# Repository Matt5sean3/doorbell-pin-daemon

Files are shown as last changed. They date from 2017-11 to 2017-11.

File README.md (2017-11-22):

# Doorbell Pin Daemon

This is a simple program for controlling a Doorbell using a Raspberry Pi. With minor modifications this system should be usable with any Linux system that can control GPIOs via sysfs. Everything from board designs to the systemd service are included. This is still in development and ideally will be deployable as just a debian package on the Pi eventually.

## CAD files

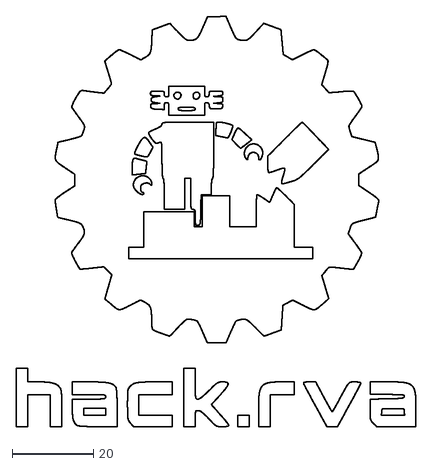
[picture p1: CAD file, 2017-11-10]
enclosure/Hackrobot.dxf
98.2 x 100.8

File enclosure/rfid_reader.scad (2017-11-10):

// Designed for the Parallax RFID Reader 28140
// A rather too expensive module

// 62.2 x 82.5 x 5.57 mm
// Use 3mm walls
// 3.5mm screw holes
// 54.5mm bolt center-to-center distance
// 75mm bolt center-to-center distance y
// 1.6mm 

// #6 machine screw holes

width = 62.3;
height = 82.6;
side_space = 1;
board_depth = 1.6;
standoff = 2;
electronics_depth = 4;
electronics_height = 15;
electronics_width = 47;
bolt_diameter = 9.5;
bolt_thickness = 3;
bolt_hole_diameter = 3.7;
plate_thickness = 3;
bolt_length = 18;

// connector hole 2.54 x 10.12
connector_width = 11;
connector_depth = 3;
connector_offset = 8;

wall_thickness = 2.5;

// to prevent rounding problems
del = 0.1;
front_thickness = max(wall_thickness, bolt_thickness + 1);
depth = bolt_length - plate_thickness;
bolt_offset = bolt_hole_diameter / 2 + 2.25;
bolt_hole_locations = [
  [bolt_offset, bolt_offset, 0],
  [width - bolt_offset, bolt_offset, 0],
  [bolt_offset, height - bolt_offset, 0],
  [width - bolt_offset, height - bolt_offset, 0]];

module rfid_reader_enclosure() {

  difference() {
    translate([-wall_thickness - side_space, -wall_thickness - side_space])
      cube([width + 2 * (wall_thickness + side_space), height + 2 * (wall_thickness + side_space), depth]);

    // void for the board and electronics
    difference() {
      translate([-side_space, -side_space, front_thickness])
        cube([2 * side_space + width, 2 * side_space + height, depth - front_thickness + del]);
      // standoffs for the board
      for(location = bolt_hole_locations) {
        translate(location)
          cylinder(d = bolt_diameter, h = front_thickness + standoff);
      }
    }

    // void for the connectors
    translate([connector_offset, -side_space - wall_thickness - del, front_thickness + board_depth + standoff - 0.25])
      cube([connector_width, wall_thickness + 2 * del, connector_depth]);

    // Bolt holes
    for(location = bolt_hole_locations) {
      translate(location)
      translate([0, 0, -del]) {
        cylinder(d = bolt_hole_diameter, h = depth, $fn = 20);
        cylinder(d = bolt_diameter, h = bolt_thickness, $fn = 6);
      }
    }

    // essentially placed manually
    translate([0, 0, -del])
    linear_extrude(height = min(0.5, wall_thickness / 2)) {
      translate([55, electronics_height, 0])
      scale(0.5)
      mirror([1, 0, 0])
      translate([-26, -18, 0])
        import("Hackrobot.dxf");
    }

  }
}

module rfid_spacer() {
  spacer_height = depth - front_thickness - standoff - board_depth;
  difference() {
    cylinder(d = bolt_diameter, h = spacer_height, $fn = 20);
    translate([0, 0, -del])
    cylinder(d = bolt_hole_diameter, h = spacer_height + 2 * del, $fn = 20);
  }
}

*rfid_reader_enclosure();

for(location = bolt_hole_locations) {
  translate([0, 0, front_thickness + standoff + board_depth])
  translate(location)
    rfid_spacer();
}

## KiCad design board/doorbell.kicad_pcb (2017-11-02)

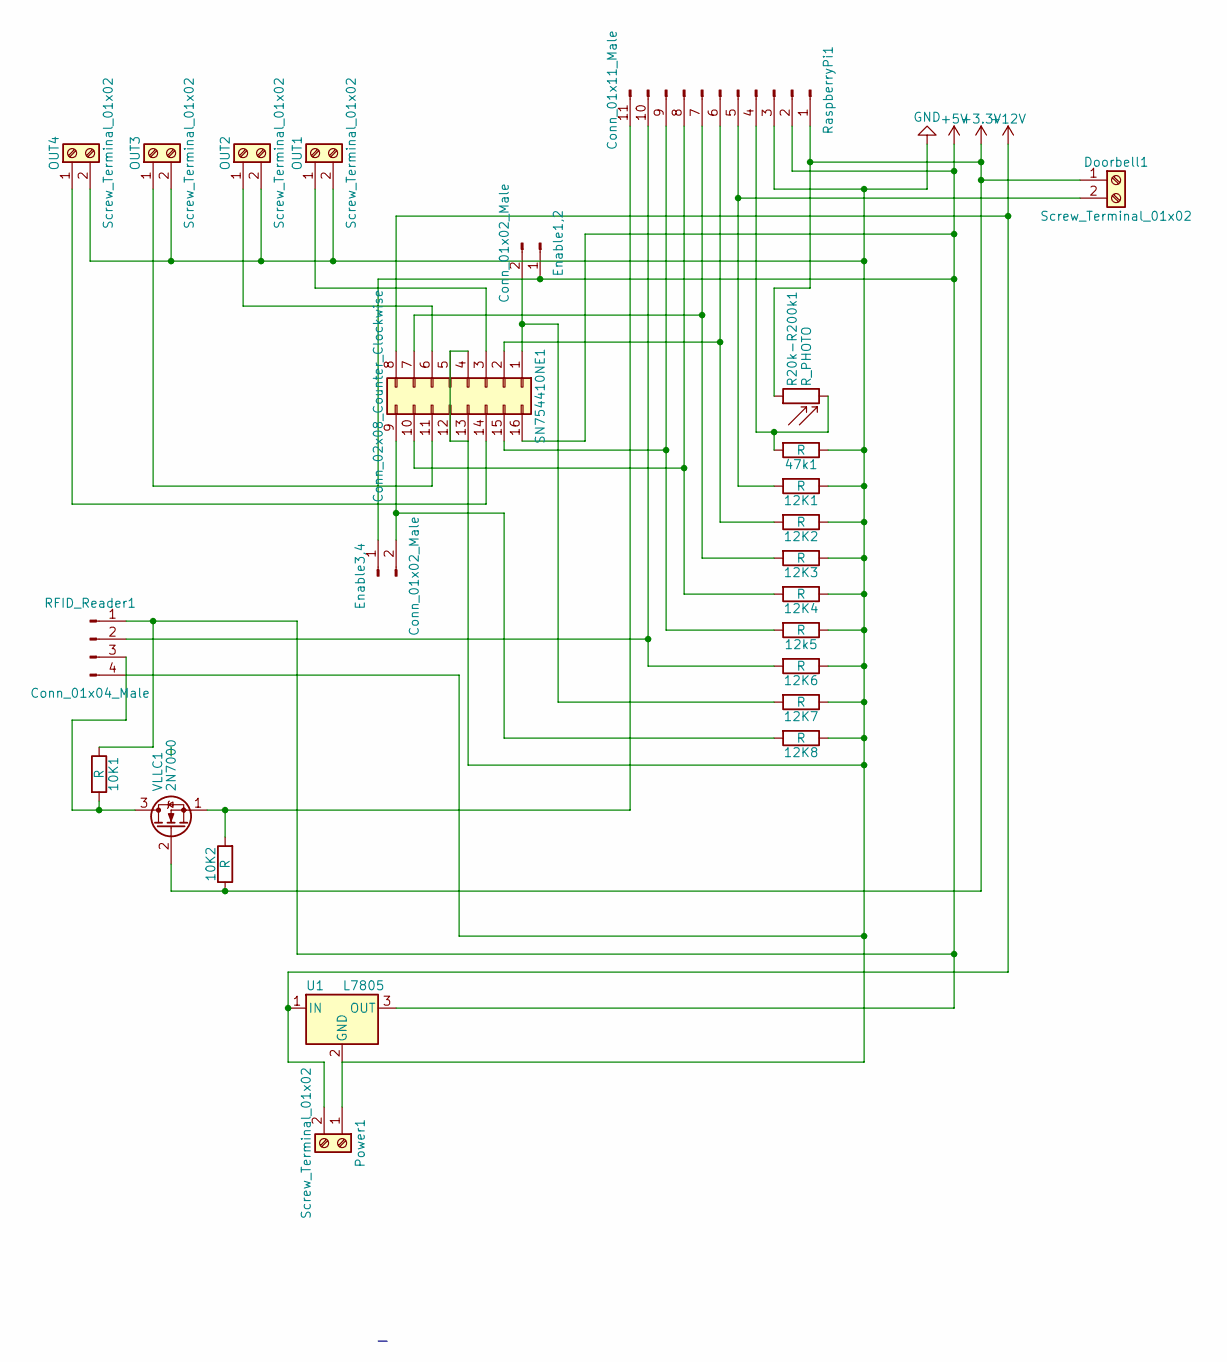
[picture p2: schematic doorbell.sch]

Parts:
10K1, 10K2: R; R_Axial_DIN0204_L3.6mm_D1.6mm_P7.62mm_Horizontal
12K1, 12K2, 12K3, 12K4, 12K6, 12K7, 12K8, 12k5, 47k1: R; R_Axial_DIN0207_L6.3mm_D2.5mm_P7.62mm_Horizontal
Doorbell1: Screw_Terminal_01x02; TerminalBlock_Philmore_TB132_02x5mm_Straight
Enable1,2, Enable3,4: Conn_01x02_Male; Pin_Header_Straight_1x02_Pitch2.54mm
OUT1, OUT2, OUT3, OUT4: Screw_Terminal_01x02; TerminalBlock_Philmore_TB132_02x5mm_Straight
Power1: Screw_Terminal_01x02; TerminalBlock_Philmore_TB132_02x5mm_Straight
R20k-R200k1: R_PHOTO; R_Axial_DIN0204_L3.6mm_D1.6mm_P5.08mm_Vertical
RFID_Reader1: Conn_01x04_Male; Pin_Header_Straight_1x04_Pitch2.54mm
RaspberryPi1: Conn_01x11_Male; Pin_Header_Straight_1x11_Pitch2.54mm
SN754410NE1: Conn_02x08_Counter_Clockwise; DIP-16_W7.62mm
U1: L7805; TO-220
VLLC1: 2N7000; TO-92_Inline_Wide

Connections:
+3V3: 10K2.1, Doorbell1.1, R20k-R200k1.1, RaspberryPi1.1, VLLC1.2 (G)
+5V: 10K1.1, Enable1,2.1, Enable3,4.1, RFID_Reader1.1, RaspberryPi1.2, SN754410NE1.16, U1.3 (OUT)
+12V: Power1.2, SN754410NE1.8, U1.1 (IN)
GND: 12K1.1, 12K2.1, 12K3.1, 12K4.1, 12K6.1, 12K7.1, 12K8.1, 12k5.1, 47k1.1, OUT1.2, OUT2.2, OUT3.2, OUT4.2, Power1.1, RFID_Reader1.4, RaspberryPi1.3, SN754410NE1.4, SN754410NE1.5, SN754410NE1.12, SN754410NE1.13, U1.2 (GND)
unnamed: 10K1.2, RFID_Reader1.3, VLLC1.3 (D)
unnamed: 10K2.2, RaspberryPi1.11, VLLC1.1 (S)
unnamed: 12K1.2, Doorbell1.2, RaspberryPi1.5
unnamed: 12K2.2, RaspberryPi1.6, SN754410NE1.2
unnamed: 12K3.2, RaspberryPi1.7, SN754410NE1.7
unnamed: 12K4.2, RaspberryPi1.8, SN754410NE1.10
unnamed: 12K6.2, RFID_Reader1.2, RaspberryPi1.10
unnamed: 12K7.2, Enable1,2.2, SN754410NE1.1
unnamed: 12K8.2, Enable3,4.2, SN754410NE1.9
unnamed: 12k5.2, RaspberryPi1.9, SN754410NE1.15
unnamed: 47k1.2, R20k-R200k1.2, RaspberryPi1.4
unnamed: OUT1.1, SN754410NE1.3
unnamed: OUT2.1, SN754410NE1.6
unnamed: OUT3.1, SN754410NE1.11
unnamed: OUT4.1, SN754410NE1.14

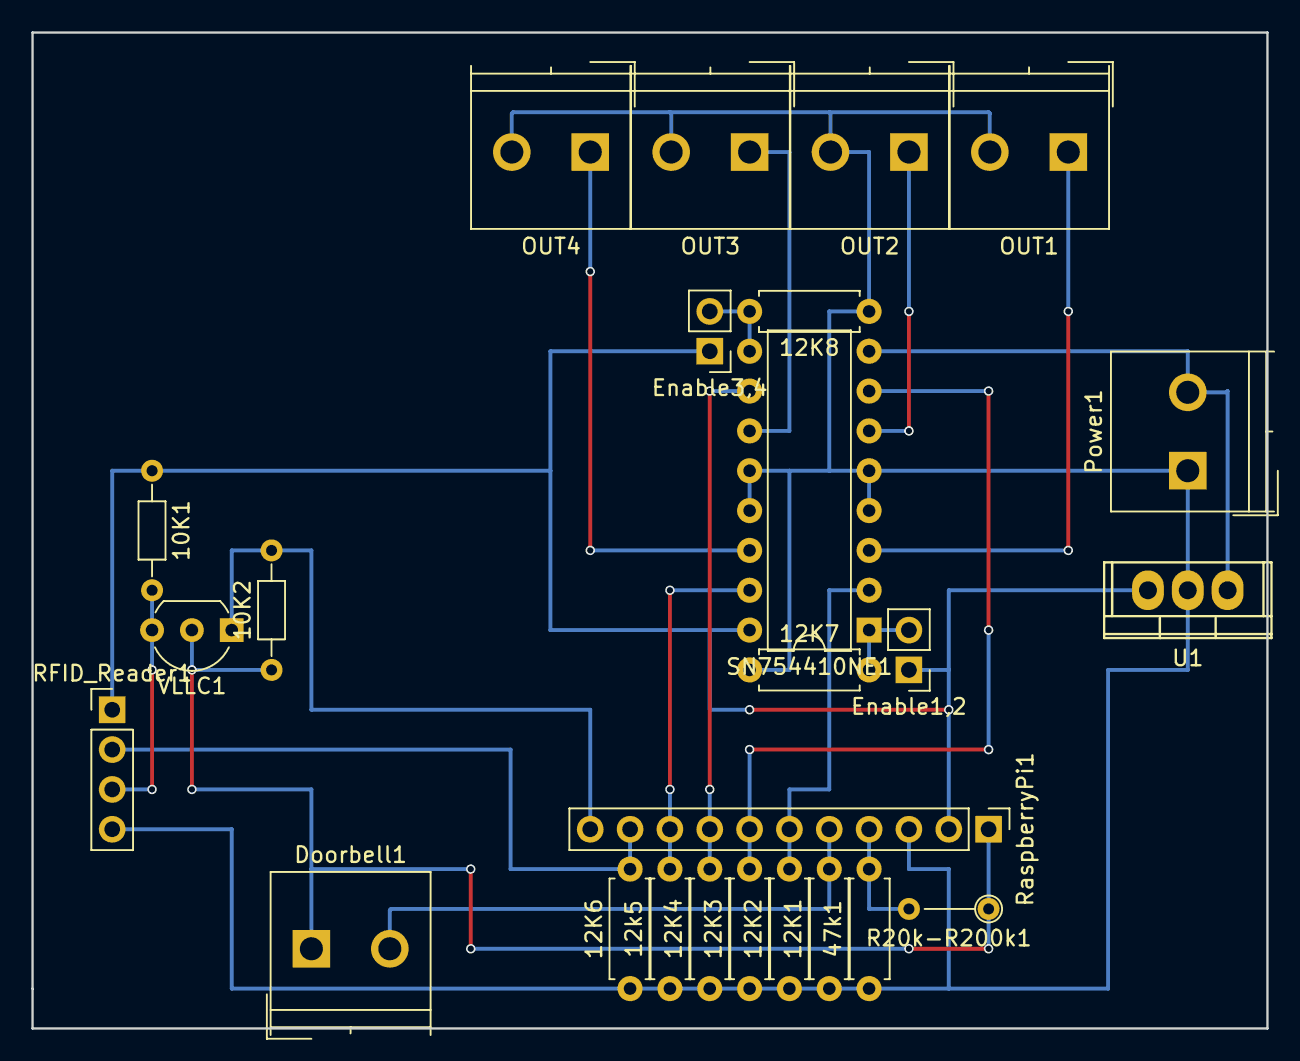
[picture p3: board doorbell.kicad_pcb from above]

Board: 2 copper layers, 78.7 x 63.5 mm, 25 parts (0 on the bottom side), 19 nets.

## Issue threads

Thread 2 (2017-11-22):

Move configuration into text files instead of being compiled in

Matt5sean3, 2017-11-22:
The current setup uses declaratively defined C structures, which is workable, but doesn't allow for switching pin configurations without recompilation of the software and in general just isn't clean.

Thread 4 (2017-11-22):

Thorough Test Cases

Matt5sean3, 2017-11-22:
Simulating a sysfs GPIO pin isn't impossible, and is probably the best way to do testing.Much of the software does seem to get coupled fairly tightly to sysfs which would make transparent re-implementation on a micro-controller fairly cumbersome.

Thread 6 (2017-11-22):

Design Board Enclosure

Matt5sean3, 2017-11-22:
A specific enclosure for the power board isn't vital, but for appearance purposes is somewhat important. The plan is for the enclosure to be 3D printed, but the proto-board that anyone else may be using to implement this design might be significantly different from what I have available.

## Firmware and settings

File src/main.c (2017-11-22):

#include "pin_daemon.h"
#include <time.h>
#include <stdio.h>

static void ring_doorbell(PinState state, void* userptr);
static void light_change(PinState state, void* userptr);

#define LIGHT_LOG "/mnt/HackRVA-NAS/lights.log"

const PinInConfiguration pin_ins[] = {
  { // light
    "4",
    "/sys/class/gpio/gpio4/direction",
    "/sys/class/gpio/gpio4/value",
    "/sys/class/gpio/gpio4/edge",
    PIN_EDGE_BOTH,

    light_change, // callback
    NULL, // callback userptr
    {0, 0}, // no debounce
    1 // ignore ephemeral changes
  },
  { // button
    "17",
    "/sys/class/gpio/gpio17/direction",
    "/sys/class/gpio/gpio17/value",
    "/sys/class/gpio/gpio17/edge",
    PIN_EDGE_BOTH,

    ring_doorbell, // callback
    NULL, // callback userptr
    {0, 200000000}, // 20ms debounce
    1 // ignore ephemeral changes
  }
};

const PinOutConfiguration pin_outs[] = {
  { // back doorbell
    "18",
    "/sys/class/gpio/gpio18/direction",
    "/sys/class/gpio/gpio18/value"
  },
  { // front doorbell
    "27",
    "/sys/class/gpio/gpio27/direction",
    "/sys/class/gpio/gpio27/value"
  }
};

const PinConfiguration configuration = {
  86400000, /* an hour in milliseconds 1000 * 60 * 60 * 24 */
  // export file
  "/sys/class/gpio/export",
  // unexport file
  "/sys/class/gpio/unexport",
  // number of input pins
  2,
  pin_ins,
  // number of output pins
  2,
  pin_outs
};

int main(int argc, char** argv) {

  pin_run(&configuration);

}

// Hold the ring for 200ms
const struct timespec ring_hold = {
  0,
  200000000
};

static void ring_doorbell(PinState state, void* userptr) {
  if(state != PIN_STATE_HIGH)
    return;
  pin_set_state(&pin_outs[1], PIN_STATE_HIGH);
  nanosleep(&ring_hold, NULL);
  pin_set_state(&pin_outs[1], PIN_STATE_LOW);
}

static void light_change(PinState state, void* userptr) {
  FILE* f = fopen(LIGHT_LOG, "a");
  if(f == NULL)
    printf("Failed to open LIGHT_LOG file: %s\n", LIGHT_LOG);
  struct timespec current_time;
  clock_gettime(CLOCK_REALTIME, &current_time);
  fprintf(f, "%lld:%9ld %s\n", (long long) current_time.tv_sec, current_time.tv_nsec, state == PIN_STATE_HIGH ? "B" : "D");
  fclose(f);
}

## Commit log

2017-11-02 Add board design files
    [doorbell.kicad_pcb, doorbell.sch]
2017-11-10 Created enclosure design
    [Hackrobot.dxf, rfid_reader.scad]
2017-11-22 Changed pin configuration to use pins toward the top of the board
2017-11-22 Fixed format of light log file
    [main.c]
